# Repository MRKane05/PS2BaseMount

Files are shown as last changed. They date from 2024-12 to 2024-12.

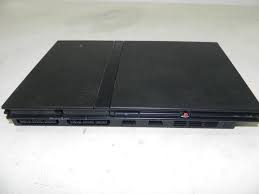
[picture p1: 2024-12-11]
PS2Console.jpeg

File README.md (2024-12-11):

This is a dump of the KiCad project for the Junkstation PS2 project I made a few years ago. I'm really just backing it up for prosperity. 
I'm taking no responsibility for this and it really should be used only as reference.

It's worth noting that there are a couple of mistakes on the board that I haven't fixed:
-The Ethernet wiring for the Mango isn't correct, and troubleshooting it was exceedingly difficult, so much so that I didn't write it down when I got it right, I just put the lid on it
-The Ethernet lines for the Mango shouldn't be pulled down to Ground but pulled to the "R0" pin on the Mango. This allows a successful ethernet connection
-The SD Card slot wired up for game loading through the memory card port is correctly wired

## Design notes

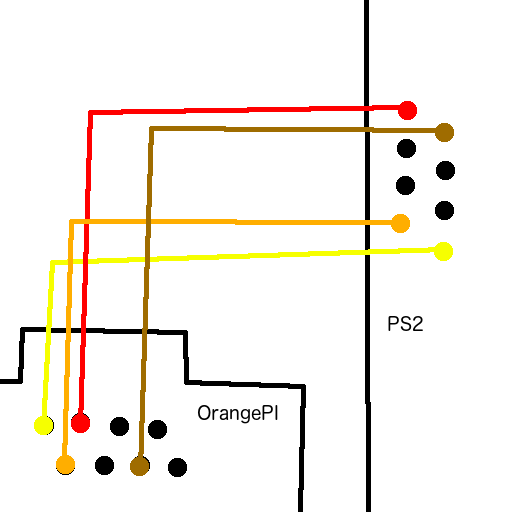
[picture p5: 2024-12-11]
PS2toOrangePi.png

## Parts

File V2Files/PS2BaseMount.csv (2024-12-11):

Comment | Designator | Footprint | LCSC
10U | C1 | Capacitor_SMD:C_1206_3216Metric_Pad1.42x1.75mm_HandSolder
CP_220uF | C10 | Capacitor_THT:CP_Radial_D8.0mm_P3.50mm
470n | C2,C3,C9 | Capacitor_SMD:C_1206_3216Metric_Pad1.42x1.75mm_HandSolder | C1871
C1u | C4,C5,C6 | Capacitor_SMD:C_1206_3216Metric_Pad1.42x1.75mm_HandSolder | C1848
CP_680uF | C7 | Capacitor_THT:CP_Radial_D8.0mm_P2.50mm
C470u | C8 | Capacitor_THT:CP_Radial_D8.0mm_P2.50mm
DIODE | D1 | Crystal:Crystal_SMD_5032-2Pin_5.0x3.2mm_HandSoldering
LED_GREEN | D2 | LED_THT:LED_D3.0mm
LED_YELLOW | D3 | LED_THT:LED_D3.0mm
LED_RED | D4 | LED_THT:LED_D3.0mm
D_Schottky | D5 | Crystal:Crystal_SMD_5032-2Pin_5.0x3.2mm_HandSoldering | C8678
BATT_LED_A | D6 | LED_THT:LED_D3.0mm
BATT_LED_B | D7 | LED_THT:LED_D3.0mm
RJ45 | J1,J5 | PS2BaseMount:RJ45_Floating
Conn_01x06_Female | J2,J8 | Connector_PinHeader_2.54mm:PinHeader_1x06_P2.54mm_Horizontal
USB_B | J4 | PS2BaseMount:USB_A_Custom_Throughhole_MountGuide
DB15_Female_HighDensity | J6 | PS2BaseMount:ScreenBoardArea
INDUCTOR_33uH | L1 | Inductor_SMD:L_12x12mm_H8mm | C169375
PS2AVPort_SideMount | M1 | PS2BaseMount:PS2_AVPort_Complete_MountSilk
PS2AVPort | M2 | PS2BaseMount:PS2_AVPort_Complete
TS_LFT | M3 | PS2BaseMount:JST_1.25_5Pin
TS_RHT | M4 | PS2BaseMount:JST_1.25_5Pin
TRIGGERS_LFT | M5 | PS2BaseMount:JST_1.25_3Pin
TRIGGERS_RIGHT | M6 | PS2BaseMount:JST_1.25_3Pin
Fan | M7 | PS2BaseMount:JST_1.5_2Pin
PS2_MemCardMount | P1 | PS2BaseMount:PS2_MemCardMountPoints
PS2_ControlMount | P2,P3 | PS2BaseMount:PS2_BoardMountFootprint
2N7000 | Q1,Q4,Q5,Q6 | PS2BaseMount:2N7000_HandSolder
Q_NMOS_GDS | Q2 | Package_TO_SOT_THT:TO-220F-3_Vertical
2N2219 | Q3 | PS2BaseMount:2N7000_HandSolder
100K | R1,R4 | Resistor_SMD:R_1206_3216Metric_Pad1.42x1.75mm_HandSolder
220 | R10 | Resistor_SMD:R_1206_3216Metric_Pad1.42x1.75mm_HandSolder
R10K | R11,R12,R13,R17,R18,R19 | Resistor_SMD:R_1206_3216Metric_Pad1.42x1.75mm_HandSolder
R100K | R14,R15 | Resistor_SMD:R_1206_3216Metric_Pad1.42x1.75mm_HandSolder
1K | R2,R6 | Resistor_SMD:R_1206_3216Metric_Pad1.42x1.75mm_HandSolder
4.7K | R5 | Resistor_SMD:R_2010_5025Metric_Pad1.52x2.65mm_HandSolder
4.7K | R7 | Diode_SMD:D_2010_5025Metric_Pad1.52x2.65mm_HandSolder
R220 | R8,R9 | Resistor_SMD:R_1206_3216Metric_Pad1.42x1.75mm_HandSolder
INTERACTION | SW1 | PS2BaseMount:SMT_2X4X3.5MM
START | SW2 | PS2BaseMount:SquishyTact
SELECT | SW3 | PS2BaseMount:SquishyTact
OrangePiZero | U1 | PS2BaseMount:OrangePiZero
RJ14K | U10 | PS2BaseMount:RJ14K_Modified
18650_BatteryMount | U11,U12 | PS2BaseMount:18650_3xHolderV3
DPAD | U13 | PS2BaseMount:DPad_Buttons
RumbleA | U14 | PS2BaseMount:JST_1.5_2Pin
RumbleB | U15 | PS2BaseMount:JST_1.5_2Pin
GNDMount | U7,U16,U24,U25,U26 | PS2BaseMount:GND
ScreenPWM | U17 | PS2BaseMount:JST_1.5_2Pin
PIC_14 | U18 | Package_DIP:DIP-14_W7.62mm_LongPads
PS2_RESET | U19 | PS2BaseMount:GND
PJ30240 | U2 | PS2BaseMount:AudioJack_PJ30240
LM2596T-5 | U20 | Package_TO_SOT_SMD:TO-263-5_TabPin3 | C10002
GND_IN | U21 | PS2BaseMount:MountPoint
BATT_IN | U22 | PS2BaseMount:MountPoint
5vMount | U23 | PS2BaseMount:MountPoint
Audio_Left | U3 | PS2BaseMount:JST_1.5_2Pin
Audio_Right | U4 | PS2BaseMount:JST_1.5_2Pin
PAM8403 | U5 | w_smd_dil:so-16 | C348830
DS18B20 | U6 | Package_TO_SOT_THT:TO-92_Inline
PIC16F18876-I_PT | U8 | PS2BaseMount:PIC16F18876-I_PT
XOST_Buttons | U9 | PS2BaseMount:XOST_ButtonsV2

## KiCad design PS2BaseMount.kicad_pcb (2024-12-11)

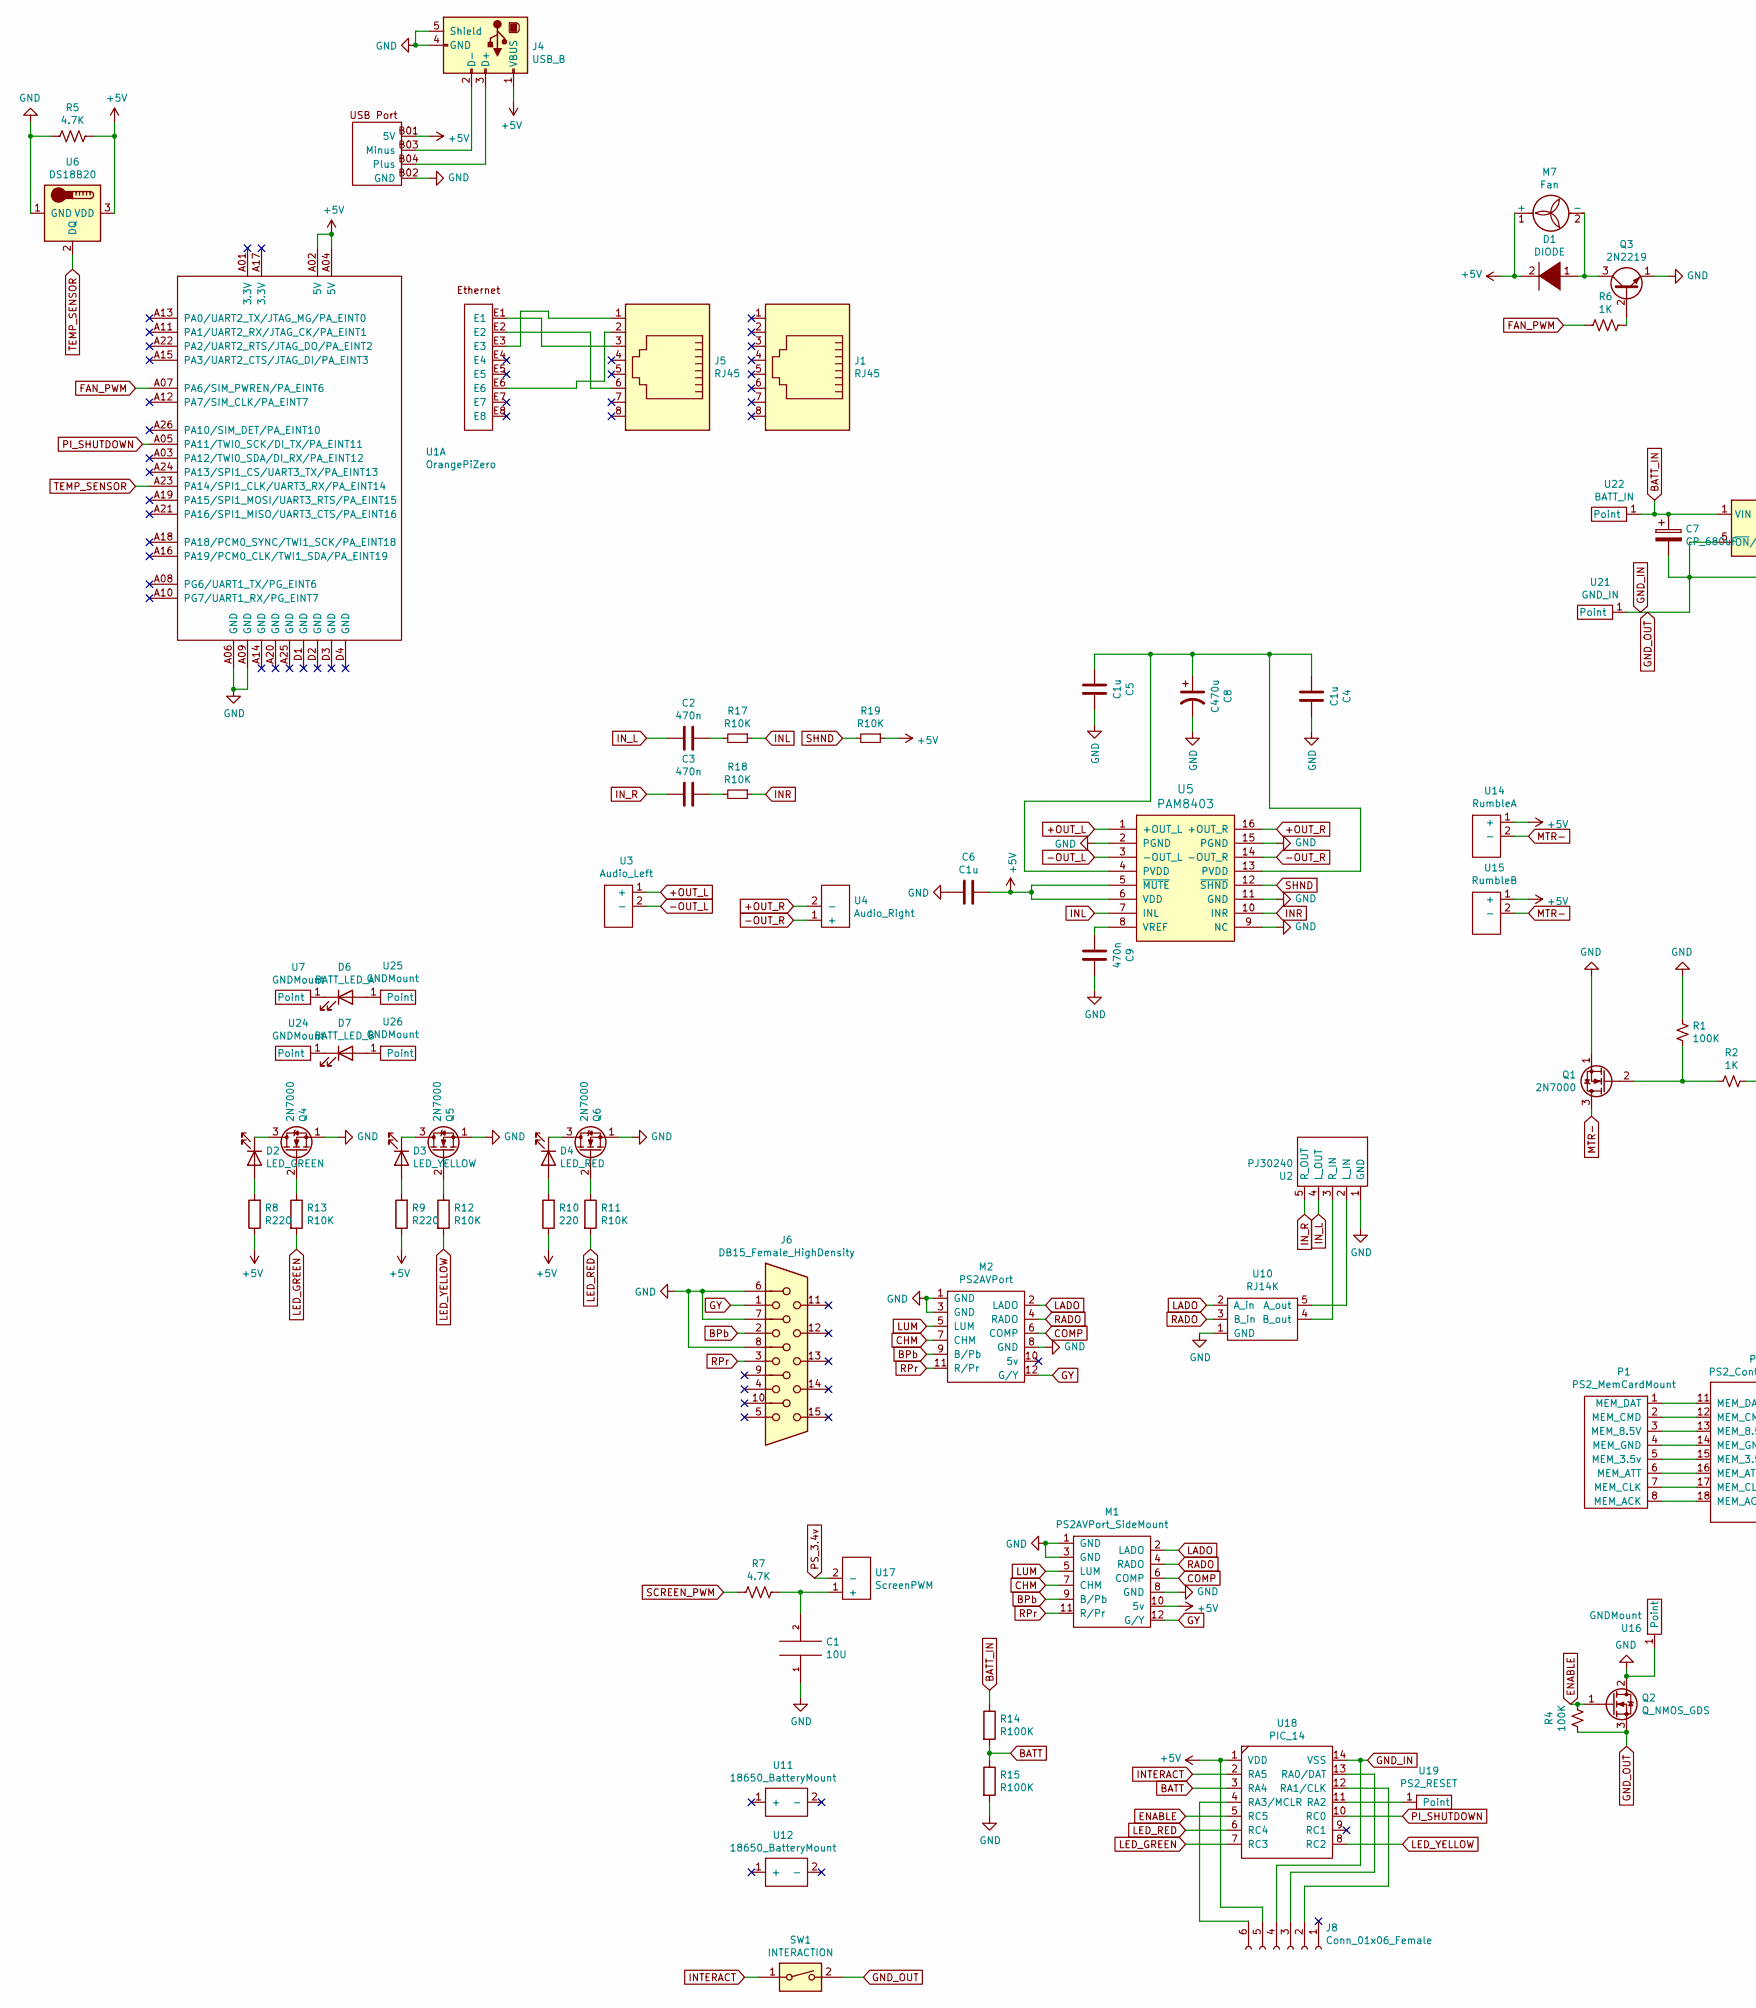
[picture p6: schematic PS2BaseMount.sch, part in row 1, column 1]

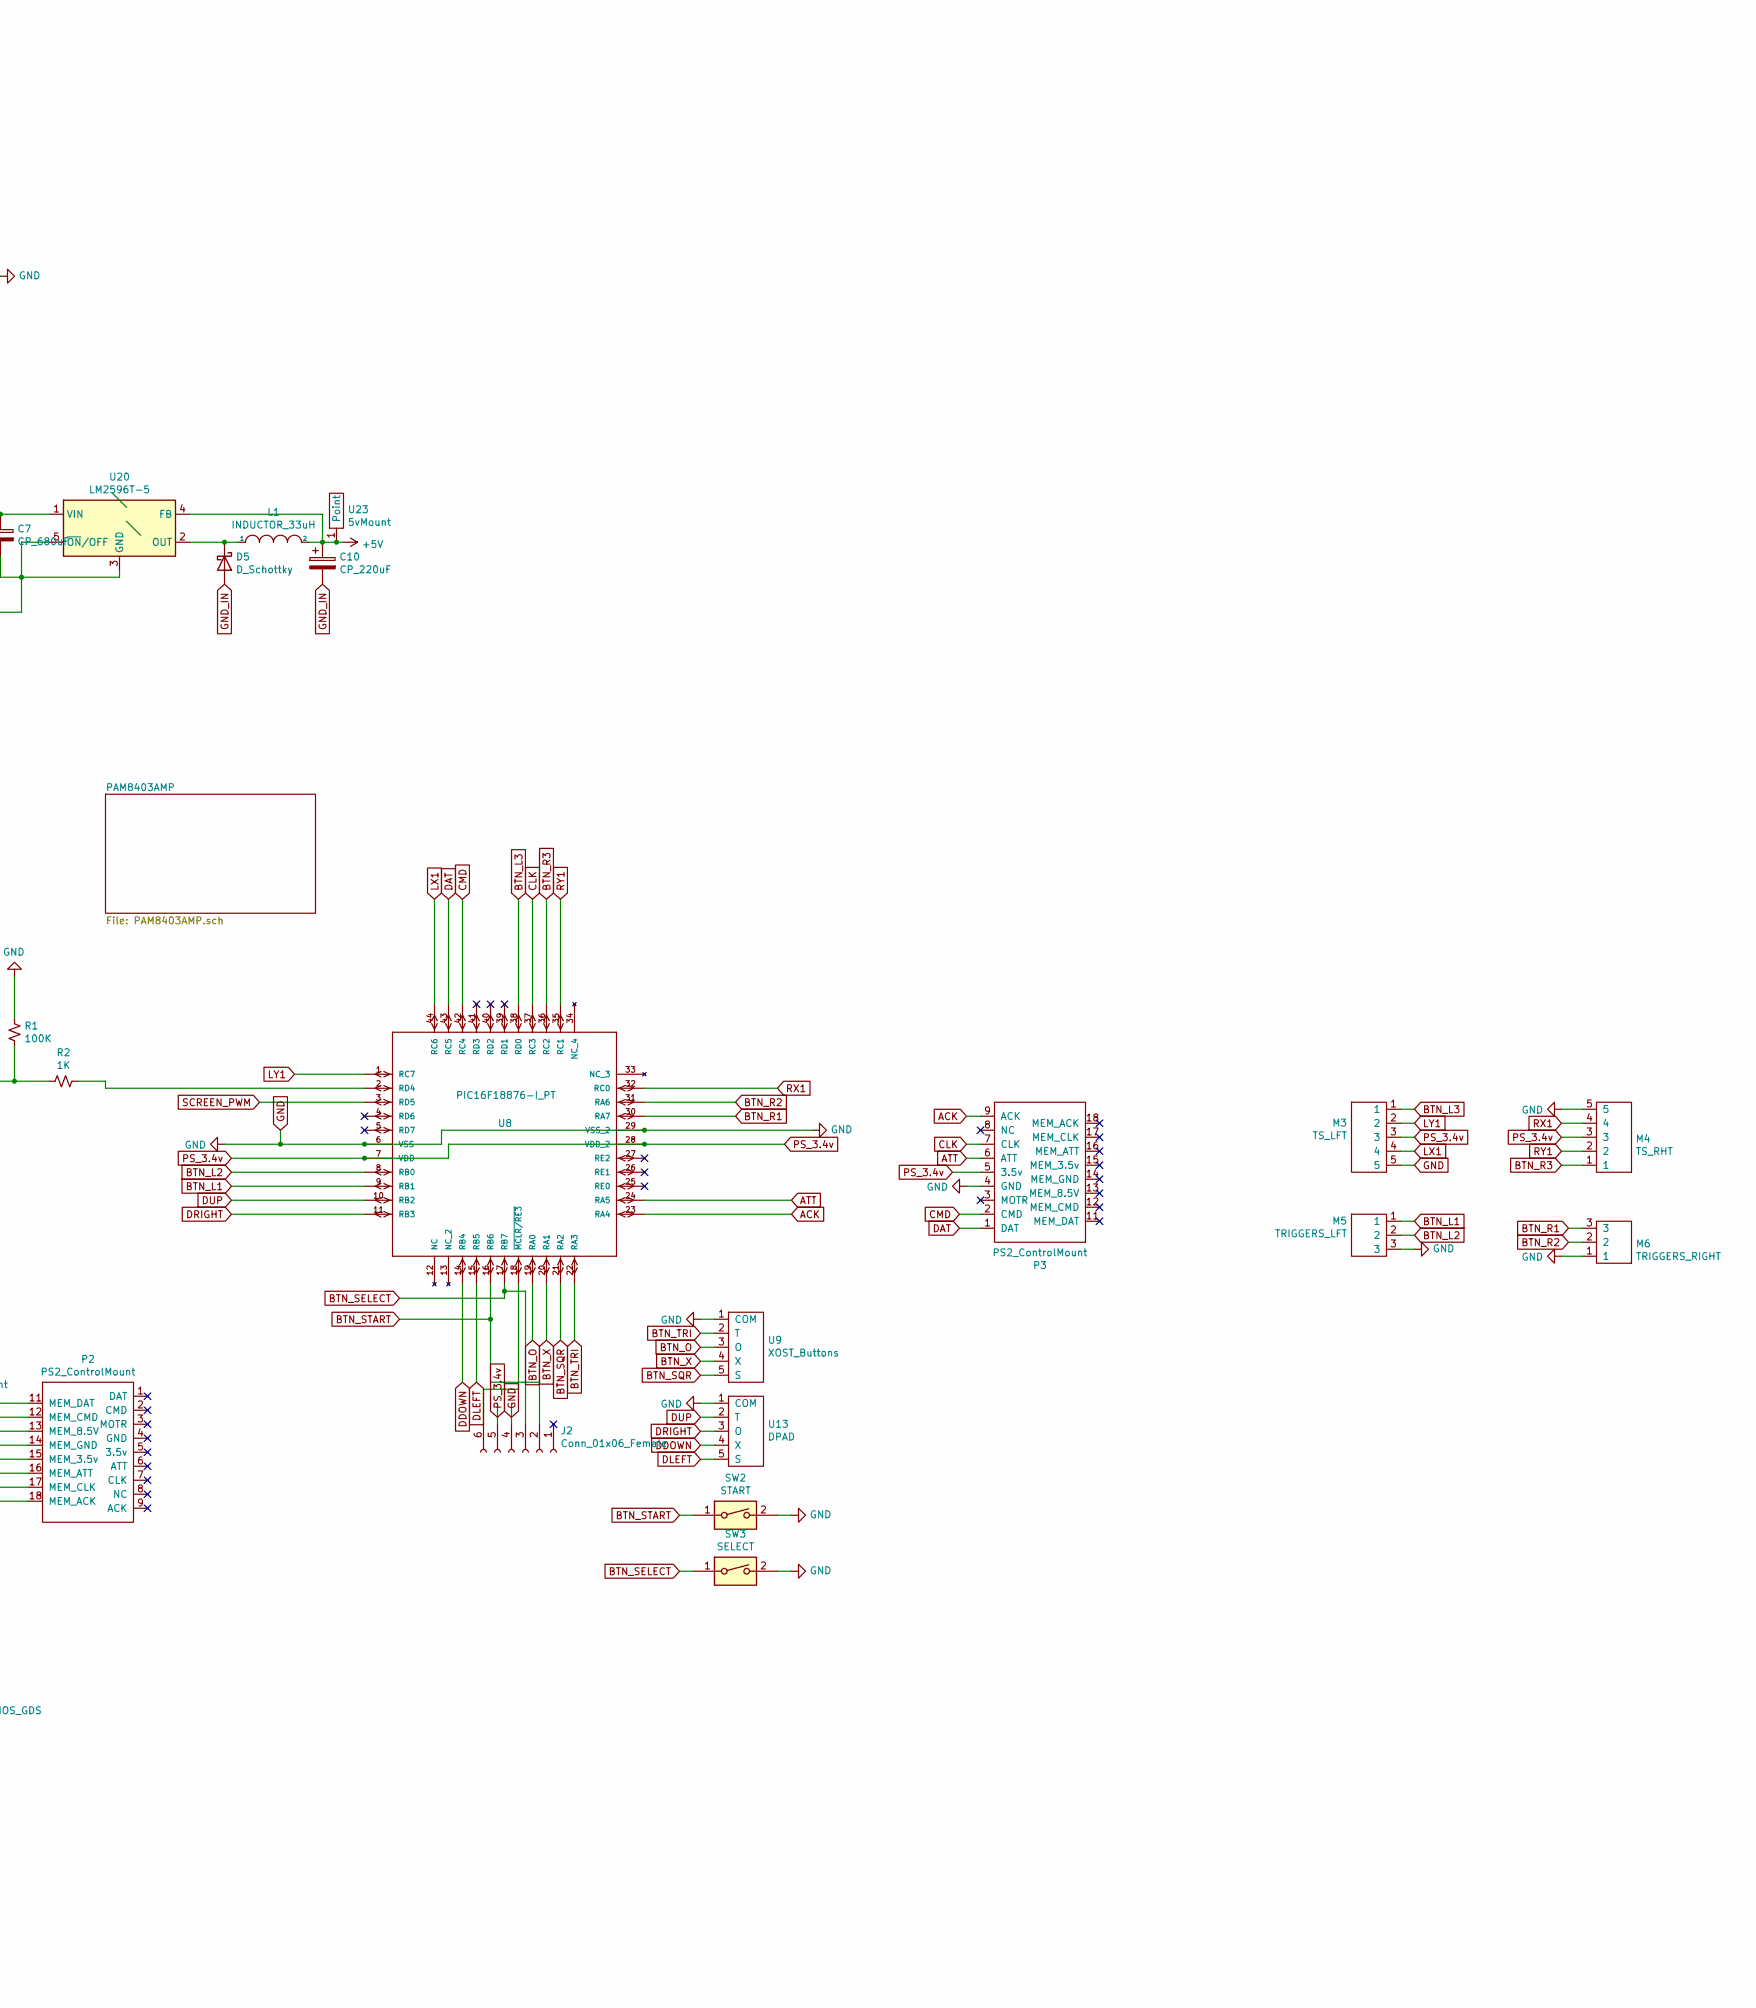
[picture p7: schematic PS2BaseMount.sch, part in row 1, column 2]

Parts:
C1: 10U; C_1206_3216Metric_Pad1.42x1.75mm_HandSolder
C2, C3, C9: 470n; C_1206_3216Metric_Pad1.42x1.75mm_HandSolder; LCSC C1871
C4, C5, C6: C1u; C_1206_3216Metric_Pad1.42x1.75mm_HandSolder; LCSC C1848
C7: CP_680uF; CP_Radial_D8.0mm_P2.50mm
C8: C470u; CP_Radial_D8.0mm_P2.50mm
C10: CP_220uF; CP_Radial_D8.0mm_P3.50mm
D1: DIODE; Crystal_SMD_5032-2Pin_5.0x3.2mm_HandSoldering
D2: LED_GREEN; LED_D3.0mm
D3: LED_YELLOW; LED_D3.0mm
D4: LED_RED; LED_D3.0mm
D5: D_Schottky; Crystal_SMD_5032-2Pin_5.0x3.2mm_HandSoldering; LCSC C8678
D6: BATT_LED_A; LED_D3.0mm
D7: BATT_LED_B; LED_D3.0mm
J1, J5: RJ45; RJ45_Floating
J2, J8: Conn_01x06_Female; PinHeader_1x06_P2.54mm_Horizontal
J4: USB_B; USB_A_Custom_Throughhole_MountGuide
J6: DB15_Female_HighDensity; ScreenBoardArea
L1: INDUCTOR_33uH; L_12x12mm_H8mm; LCSC C169375
M1: PS2AVPort_SideMount; PS2_AVPort_Complete_MountSilk
M2: PS2AVPort; PS2_AVPort_Complete
M3: TS_LFT; JST_1.25_5Pin
M4: TS_RHT; JST_1.25_5Pin
M5: TRIGGERS_LFT; JST_1.25_3Pin
M6: TRIGGERS_RIGHT; JST_1.25_3Pin
M7: Fan; JST_1.5_2Pin
P1: PS2_MemCardMount; PS2_MemCardMountPoints
P2, P3: PS2_ControlMount; PS2_BoardMountFootprint
Q1, Q4, Q5, Q6: 2N7000; 2N7000_HandSolder
Q2: Q_NMOS_GDS; TO-220F-3_Vertical
Q3: 2N2219; 2N7000_HandSolder
R1, R4: 100K; R_1206_3216Metric_Pad1.42x1.75mm_HandSolder
R2, R6: 1K; R_1206_3216Metric_Pad1.42x1.75mm_HandSolder
R5: 4.7K; R_2010_5025Metric_Pad1.52x2.65mm_HandSolder
R7: 4.7K; D_2010_5025Metric_Pad1.52x2.65mm_HandSolder
R8, R9: R220; R_1206_3216Metric_Pad1.42x1.75mm_HandSolder
R10: 220; R_1206_3216Metric_Pad1.42x1.75mm_HandSolder
R11, R12, R13: R10K; R_1206_3216Metric_Pad1.42x1.75mm_HandSolder
R14, R15: R100K; R_1206_3216Metric_Pad1.42x1.75mm_HandSolder
R17, R18, R19: R10K; R_1206_3216Metric_Pad1.42x1.75mm_HandSolder; LCSC C17902
SW1: INTERACTION; SMT_2X4X3.5MM
SW2: START; SquishyTact
SW3: SELECT; SquishyTact
U1: OrangePiZero
U2: PJ30240; AudioJack_PJ30240
U3: Audio_Left; JST_1.5_2Pin
U4: Audio_Right; JST_1.5_2Pin
U5: PAM8403; so-16; LCSC C348830
U6: DS18B20; TO-92_Inline
U7, U16, U24, U25, U26: GNDMount; GND
U8: PIC16F18876-I_PT
U9: XOST_Buttons; XOST_ButtonsV2
U10: RJ14K; RJ14K_Modified
U11, U12: 18650_BatteryMount; 18650_3xHolderV3
U13: DPAD; DPad_Buttons
U14: RumbleA; JST_1.5_2Pin
U15: RumbleB; JST_1.5_2Pin
U17: ScreenPWM; JST_1.5_2Pin
U18: PIC_14; DIP-14_W7.62mm_LongPads
U19: PS2_RESET; GND
U20: LM2596T-5; TO-263-5_TabPin3; LCSC C10002
U21: GND_IN; MountPoint
U22: BATT_IN; MountPoint
U23: 5vMount; MountPoint

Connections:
+5V: C6.1, C10.1, D1.2 (A), J4.1 (VBUS), J8.5, L1.2, M1.10 (5v), M7.1 (+), R5.1, R8.1, R9.1, R10.1, R19.1, U1.A02 (5V), U1.A04 (5V), U1.B01 (5V), U5.5 (~MUTE), U5.6 (VDD), U6.3 (VDD), U14.1 (+), U15.1 (+), U18.1 (VDD), U20.4 (FB), U23.1
+OUT_L: U3.1 (+), U5.1 (+OUT_L)
+OUT_R: U4.2 (-), U5.16 (+OUT_R)
-OUT_L: U3.2 (-), U5.3 (-OUT_L)
-OUT_R: U4.1 (+), U5.14 (-OUT_R)
ACK: P3.9 (ACK), U8.23 (RA4)
ATT: P3.6 (ATT), U8.24 (RA5)
BATT: R14.2, R15.1, U18.3 (RA4)
BATT_IN: C7.1, R14.1, U20.1 (VIN), U22.1
BPb: J6.2, M1.9 (B/Pb), M2.9 (B/Pb)
BTN_L1: M5.1, U8.9 (RB1)
BTN_L2: M5.2, U8.8 (RB0)
BTN_L3: M3.1, U8.38 (RD0)
BTN_O: U8.19 (RA0), U9.3 (O)
BTN_R1: M6.3, U8.30 (RA7)
BTN_R2: M6.2, U8.31 (RA6)
BTN_R3: M4.1, U8.36 (RC2)
BTN_SELECT: J2.3, SW3.1, U8.17 (RB7)
BTN_SQR: U8.21 (RA2), U9.5 (S)
BTN_START: J2.2, SW2.1, U8.16 (RB6)
BTN_TRI: U8.22 (RA3), U9.2 (T)
BTN_X: U8.20 (RA1), U9.4 (X)
CHM: M1.7 (CHM), M2.7 (CHM)
CLK: P3.7 (CLK), U8.37 (RC3)
CMD: P3.2 (CMD), U8.42 (RC4)
COMP: M1.6 (COMP), M2.6 (COMP)
DAT: P3.1 (DAT), U8.43 (RC5)
DDOWN: U8.14 (RB4), U13.4 (X)
DLEFT: U8.15 (RB5), U13.5 (S)
DRIGHT: U8.11 (RB3), U13.3 (O)
DUP: U8.10 (RB2), U13.2 (T)
ENABLE: Q2.1 (G), R4.1, U18.5 (RC5)
FAN_PWM: R6.2, U1.A07 (PA6/SIM_PWREN/PA_EINT6)
GND: C1.1, C4.1, C5.1, C6.2, C8.2, C9.1, J2.4, J4.4 (GND), J4.5 (Shield), J6.6, J6.7, J6.8, M1.1 (GND), M1.3 (GND), M1.8 (GND), M2.1 (GND), M2.3 (GND), M2.8 (GND), M3.5, M4.5, M5.3, M6.1, P3.4 (GND), Q1.1 (S), Q2.2 (D), Q3.1 (E), Q4.1 (S), Q5.1 (S), Q6.1 (S), R1.1, R5.2, R15.2, SW2.2, SW3.2, U1.A06 (GND), U1.A09 (GND), U1.B02 (GND), U2.1 (GND), U5.2 (PGND), U5.9 (NC), U5.11 (GND), U5.15 (PGND), U6.1 (GND), U8.6 (VSS), U8.29 (VSS_2), U9.1 (COM), U10.1 (GND), U13.1 (COM), U16.1
GND_IN: C7.2, C10.2, D5.2 (A), J8.4, Q2.3 (S), R4.2, SW1.2, U18.14 (VSS), U20.3 (GND), U20.5 (~ON~/OFF), U21.1
GY: J6.1, M1.12 (G/Y), M2.12 (G/Y)
INL: R17.1, U5.7 (INL)
INR: R18.1, U5.10 (INR)
INTERACT: SW1.1, U18.2 (RA5)
IN_L: C2.2, U2.4 (L_OUT)
IN_R: C3.2, U2.5 (R_OUT)
LADO: M1.2 (LADO), M2.2 (LADO), U10.2 (A_in)
LED_GREEN: R13.2, U18.7 (RC3)
LED_RED: R11.2, U18.6 (RC4)
LED_YELLOW: R12.2, U18.8 (RC2)
LUM: M1.5 (LUM), M2.5 (LUM)
LX1: M3.4, U8.44 (RC6)
LY1: M3.2, U8.1 (RC7)
MTR-: Q1.3 (D), U14.2 (-), U15.2 (-)
unnamed: C1.2, R7.1, U17.1 (+)
unnamed: C2.1, R17.2
unnamed: C3.1, R18.2
unnamed: C4.2, C5.2, C8.1, U5.4 (PVDD), U5.13 (PVDD)
unnamed: C9.2, U5.8 (VREF)
unnamed: D1.1 (K), M7.2 (-), Q3.3 (C)
unnamed: D2.1 (K), Q4.3 (D)
unnamed: D2.2 (A), R8.2
unnamed: D3.1 (K), Q5.3 (D)
unnamed: D3.2 (A), R9.2
unnamed: D4.1 (K), Q6.3 (D)
unnamed: D4.2 (A), R10.2
unnamed: D5.1 (K), L1.1, U20.2 (OUT)
unnamed: D6.1 (K), U7.1
unnamed: D6.2 (A), U25.1
unnamed: D7.1 (K), U24.1
unnamed: D7.2 (A), U26.1
unnamed: J2.6, U8.18 (~MCLR/RE3)
unnamed: J4.2 (D-), U1.B03 (Minus)
unnamed: J4.3 (D+), U1.B04 (Plus)
unnamed: J5.1, U1.E3
unnamed: J5.2, U1.E6
unnamed: J5.3, U1.E1
unnamed: J5.6, U1.E2
unnamed: J8.2, U18.12 (RA1/CLK)
unnamed: J8.3, U18.13 (RA0/DAT)
unnamed: J8.6, U18.4 (RA3/MCLR)
unnamed: P1.1 (MEM_DAT), P2.11 (MEM_DAT)
unnamed: P1.2 (MEM_CMD), P2.12 (MEM_CMD)
unnamed: P1.3 (MEM_8.5V), P2.13 (MEM_8.5V)
unnamed: P1.4 (MEM_GND), P2.14 (MEM_GND)
unnamed: P1.5 (MEM_3.5v), P2.15 (MEM_3.5v)
unnamed: P1.6 (MEM_ATT), P2.16 (MEM_ATT)
unnamed: P1.7 (MEM_CLK), P2.17 (MEM_CLK)
unnamed: P1.8 (MEM_ACK), P2.18 (MEM_ACK)
unnamed: Q1.2 (G), R1.2, R2.2
unnamed: Q3.2 (B), R6.1
unnamed: Q4.2 (G), R13.1
unnamed: Q5.2 (G), R12.1
unnamed: Q6.2 (G), R11.1
unnamed: R2.1, U8.2 (RD4)
unnamed: U2.3 (R_IN), U10.4 (B_out)
unnamed: U2.2 (L_IN), U10.5 (A_out)
unnamed: U18.11 (RA2), U19.1
PI_SHUTDOWN: U1.A05 (PA11/TWI0_SCK/DI_TX/PA_EINT11), U18.10 (RC0)
PS_3.4v: J2.5, M3.3, M4.3, P3.5 (3.5v), U8.7 (VDD), U8.28 (VDD_2), U17.2 (-)
RADO: M1.4 (RADO), M2.4 (RADO), U10.3 (B_in)
RPr: J6.3, M1.11 (R/Pr), M2.11 (R/Pr)
RX1: M4.4, U8.32 (RC0)
RY1: M4.2, U8.35 (RC1)
SCREEN_PWM: R7.2, U8.3 (RD5)
SHND: R19.2, U5.12 (~SHND)
TEMP_SENSOR: U1.A23 (PA14/SPI1_CLK/UART3_RX/PA_EINT14), U6.2 (DQ)

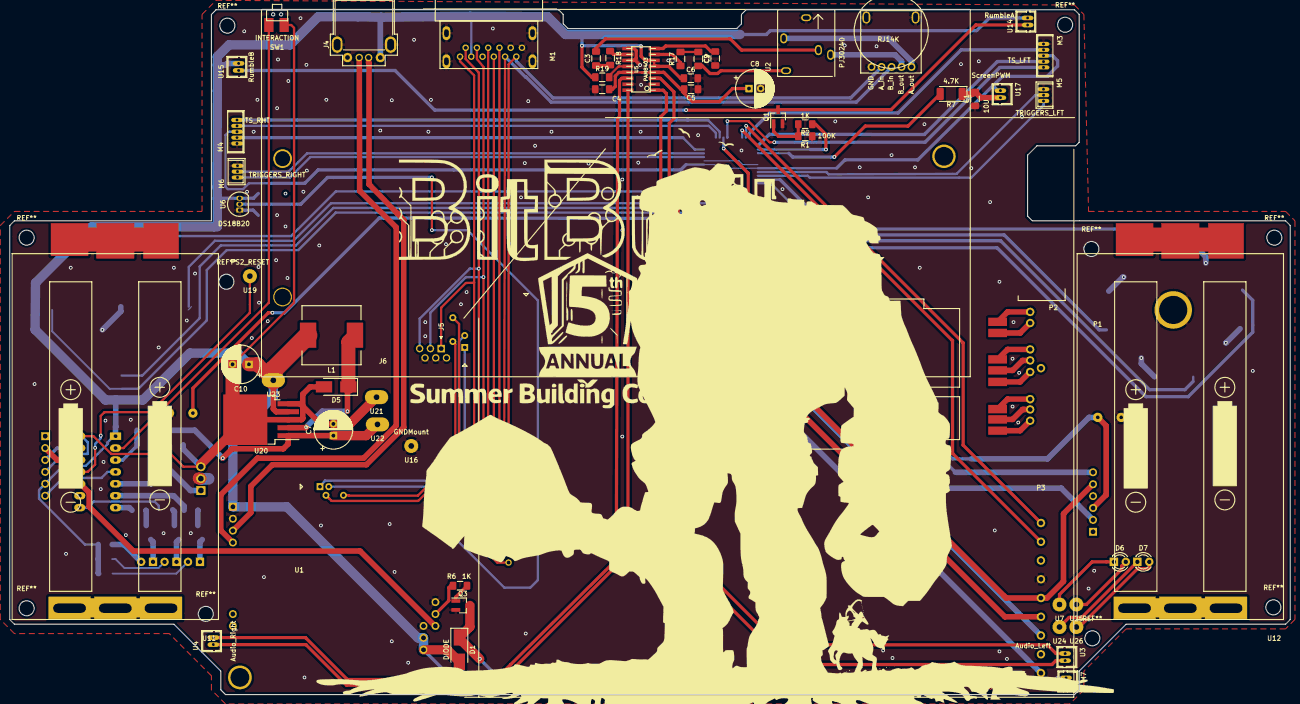
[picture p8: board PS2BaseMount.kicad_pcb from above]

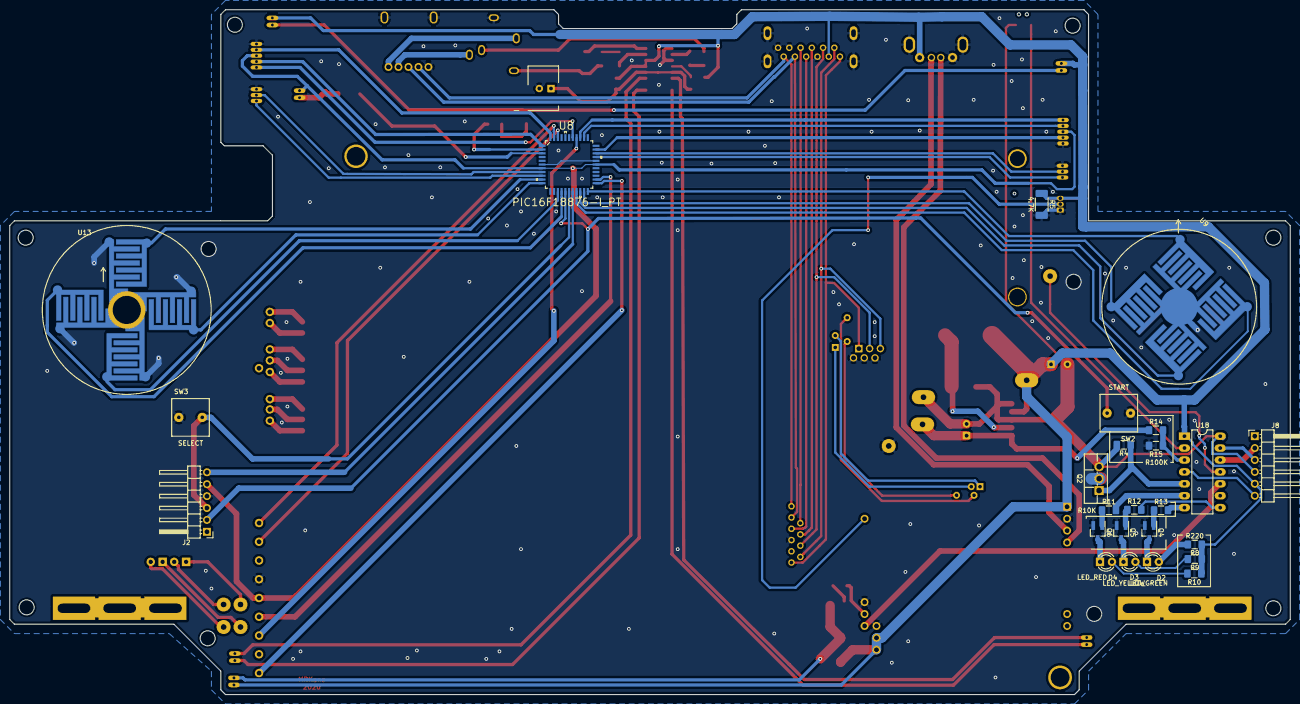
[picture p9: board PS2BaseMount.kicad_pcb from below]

Board: 2 copper layers, 273.0 x 146.0 mm, 86 parts (25 on the bottom side), 102 nets.

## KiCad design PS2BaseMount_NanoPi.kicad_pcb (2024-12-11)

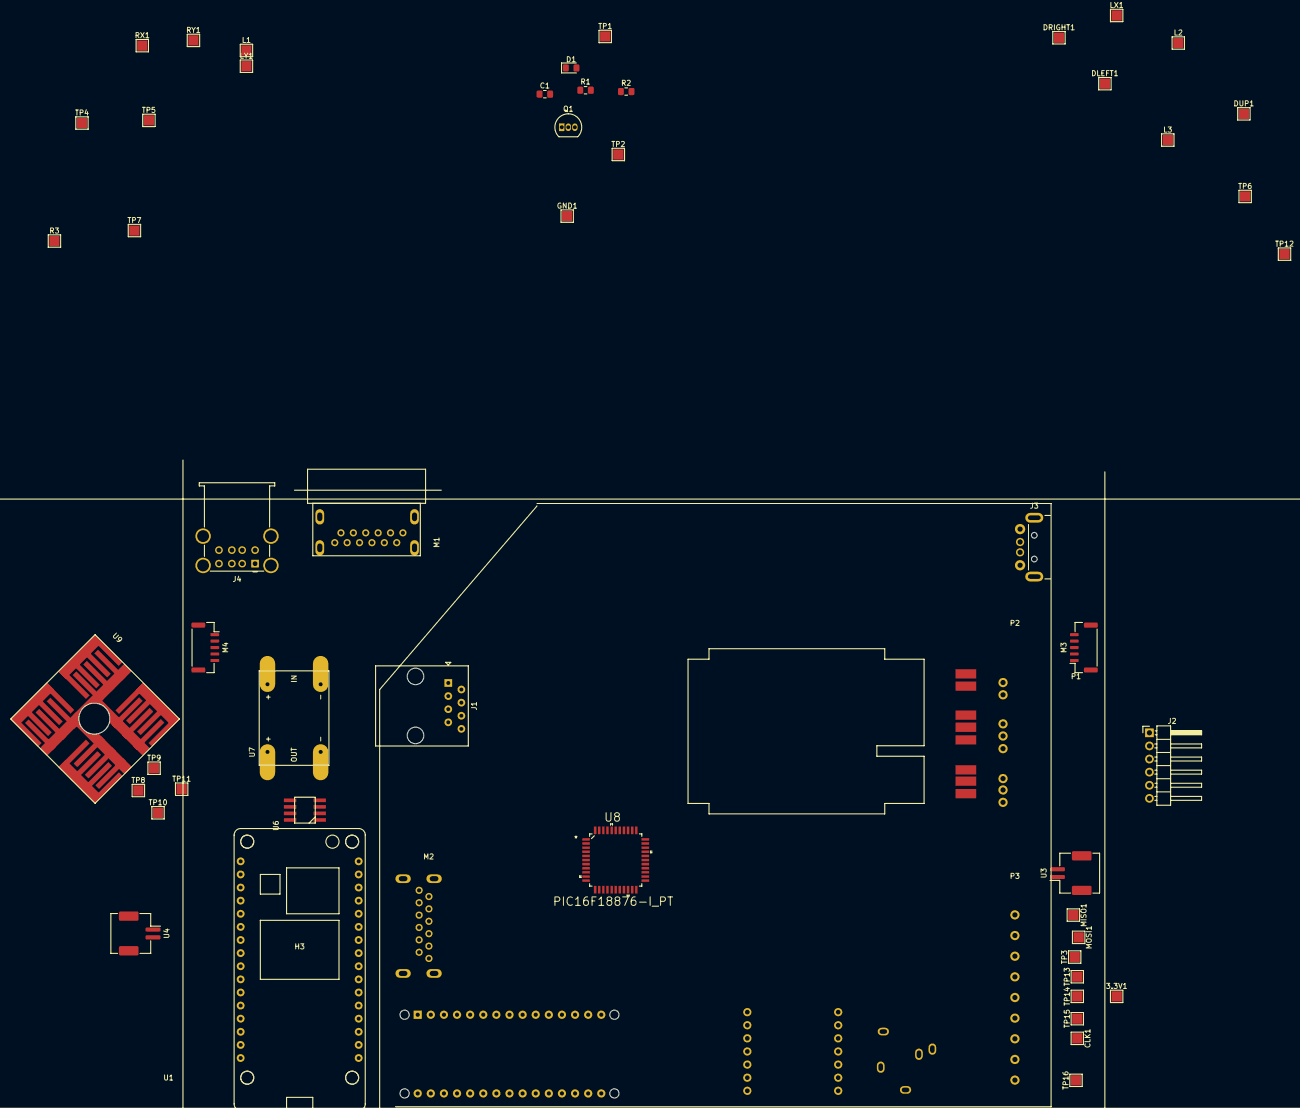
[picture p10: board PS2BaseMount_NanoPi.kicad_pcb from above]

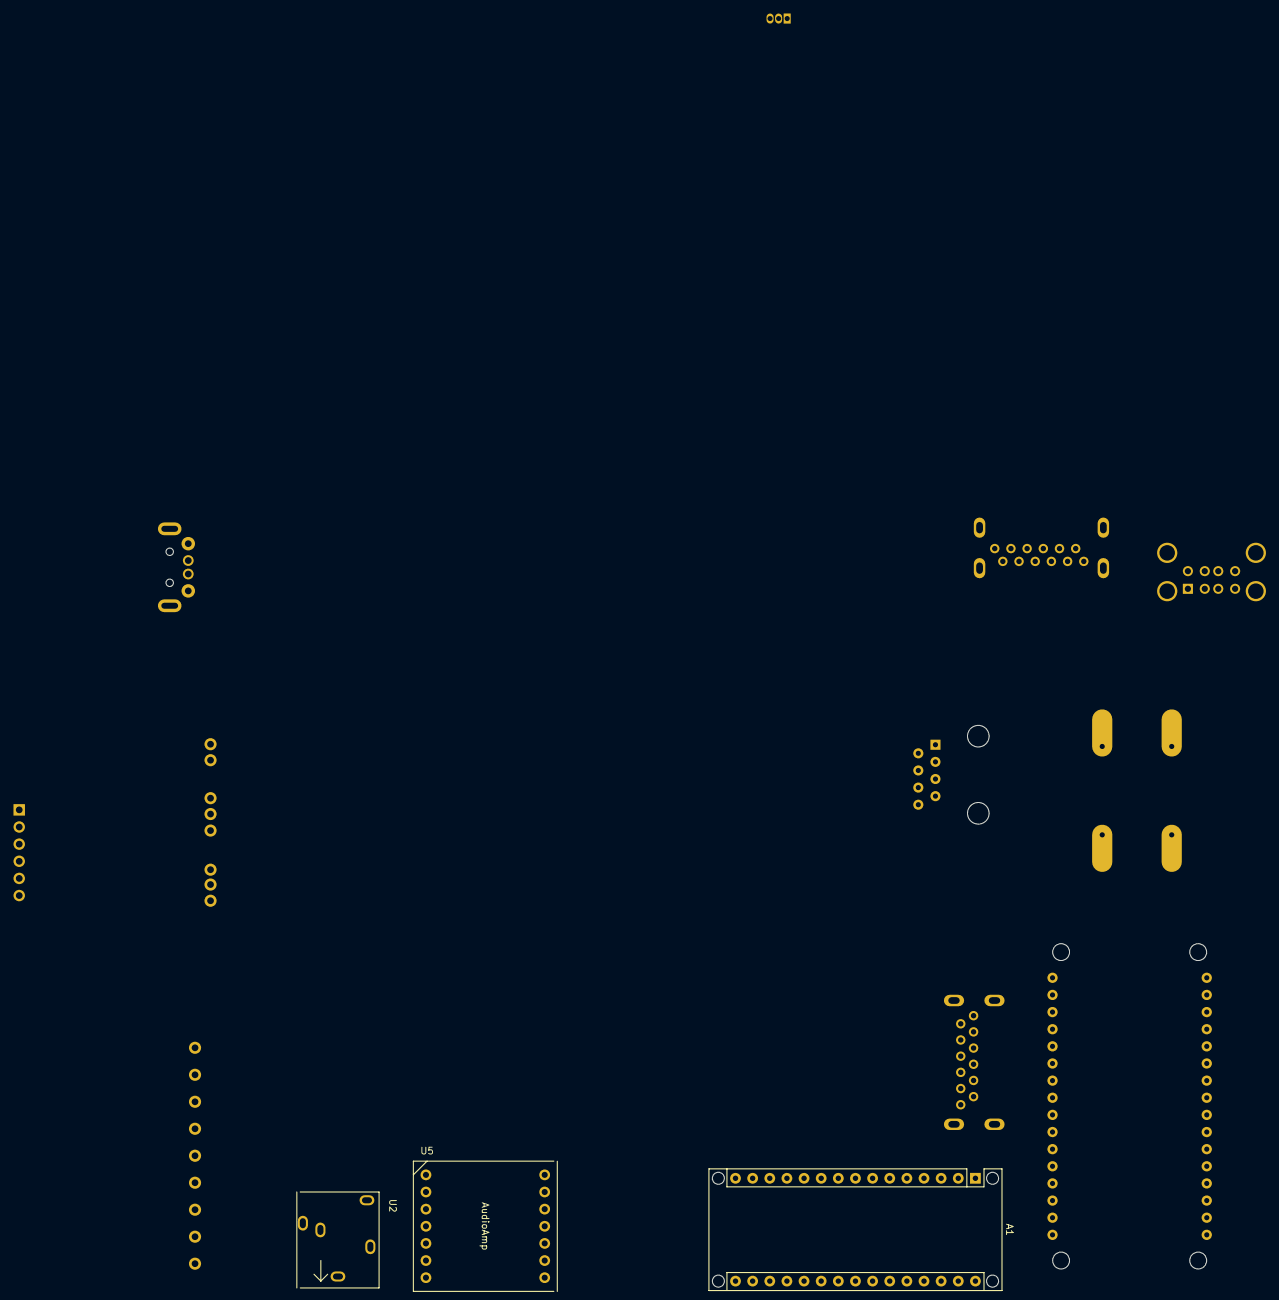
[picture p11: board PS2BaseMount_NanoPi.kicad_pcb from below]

Board: 2 copper layers, 58 parts (3 on the bottom side), 46 nets, no tracks yet.

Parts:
3.3V1: TP6; TestPoint_Pad_2.0x2.0mm
A1: Arduino_Nano_v3.x; Arduino_Nano_WithMountingHoles
C1: 10uF; C_0805_2012Metric_Pad1.15x1.40mm_HandSolder
CLK1: TP19; TestPoint_Pad_2.0x2.0mm
D1: 1N58XX; D_0805_2012Metric_Pad1.15x1.40mm_HandSolder
DLEFT1: TP7; TestPoint_Pad_2.0x2.0mm
DRIGHT1: TP8; TestPoint_Pad_2.0x2.0mm
DUP1: TP27; TestPoint_Pad_2.0x2.0mm
GND1: TP5; TestPoint_Pad_2.0x2.0mm
J1: RJ45; RJ45_Amphenol_54602-x08_Horizontal
J2: Conn_01x06_Female; PinHeader_1x06_P2.54mm_Horizontal
J3: USB_B; USB_A_Custom_Throughhole
J4: USB_A_Dual; USB_A_Wuerth_61400826021_Horizontal_Stacked
L1: TP9; TestPoint_Pad_2.0x2.0mm
L2: TP10; TestPoint_Pad_2.0x2.0mm
L3: TP20; TestPoint_Pad_2.0x2.0mm
LX1: TP26; TestPoint_Pad_2.0x2.0mm
LY1: TP23; TestPoint_Pad_2.0x2.0mm
M1: PS2AVPort_SideMount; PS2_AVPort_Complete_MountSilk
M2: PS2AVPort; PS2_AVPort_Complete
M3: TS_LFT; JST_GH_SM05B-GHS-TB_1x05-1MP_P1.25mm_Horizontal
M4: TS_RHT; JST_GH_SM05B-GHS-TB_1x05-1MP_P1.25mm_Horizontal
MISO1: TP12; TestPoint_Pad_2.0x2.0mm
MOSI1: TP13; TestPoint_Pad_2.0x2.0mm
P1: PS2_MemCardMount; PS2_MemCardMountPoints
P2, P3: PS2_ControlMount; PS2_BoardMountFootprint
Q1: 2N7000; TO-92_Inline
R1: 100K; R_0805_2012Metric_Pad1.15x1.40mm_HandSolder
R2: 1K; R_0805_2012Metric_Pad1.15x1.40mm_HandSolder
R3: TP18; TestPoint_Pad_2.0x2.0mm
RX1: TP11; TestPoint_Pad_2.0x2.0mm
RY1: TP4; TestPoint_Pad_2.0x2.0mm
TP1: MTR-; TestPoint_Pad_2.0x2.0mm
TP2: MTR+; TestPoint_Pad_2.0x2.0mm
TP3: 8.5V; TestPoint_Pad_2.0x2.0mm
TP4: R1; TestPoint_Pad_2.0x2.0mm
TP5: R2; TestPoint_Pad_2.0x2.0mm
TP6: SL; TestPoint_Pad_2.0x2.0mm
TP7: ST; TestPoint_Pad_2.0x2.0mm
TP8: SQ; TestPoint_Pad_2.0x2.0mm
TP9: TRI; TestPoint_Pad_2.0x2.0mm
TP10: X; TestPoint_Pad_2.0x2.0mm
TP11: CIR; TestPoint_Pad_2.0x2.0mm
TP12: DDOWN; TestPoint_Pad_2.0x2.0mm
TP13: GND; TestPoint_Pad_2.0x2.0mm
TP14: 3.3V; TestPoint_Pad_2.0x2.0mm
TP15: CS; TestPoint_Pad_2.0x2.0mm
TP16: ACK; TestPoint_Pad_2.0x2.0mm
U1: NanoPiDUO2; NanoPIDUO2
U2: PJ30240; AudioJack_PJ30240
U3: Audio_Left; JST_ZE_SM02B-ZESS-TBT_1x02-1MP_P1.50mm_Horizontal
U4: Audio_Right; JST_ZE_SM02B-ZESS-TBT_1x02-1MP_P1.50mm_Horizontal
U5: AudioAmp; PAM8803_AudioAmp
U6: DMosfet_AO9926B; DualMosfet AO9926B
U7: 5VBuckBoost; PS2BuckBoost
U8: PIC16F18876-I_PT
U9: XOST_Buttons

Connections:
GND: GND1.1, J2.4, P3.4, Q1.1, R1.1, TP13.1, U2.1, U3.MP, U4.MP, U8.6, U8.29
unnamed: C1.1, D1.2, Q1.3, TP1.1
unnamed: C1.2, D1.1, P3.3, TP2.1, TP3.1
unnamed: CLK1.1, P3.7, U8.37
unnamed: DLEFT1.1, U8.8
unnamed: DRIGHT1.1, U8.9
unnamed: DUP1.1, U8.31
unnamed: J2.2, TP6.1, U8.16
unnamed: J2.3, TP7.1, U8.17
unnamed: J2.6, U8.18
unnamed: L1.1, U8.10
unnamed: L2.1, U8.11
unnamed: L3.1, U8.36
unnamed: LX1.1, U8.32
unnamed: LY1.1, U8.35
unnamed: M2.2, U5.8
unnamed: M2.4, U5.10
unnamed: MISO1.1, P3.1, U8.43
unnamed: MOSI1.1, P3.2, U8.42
unnamed: P1.1, P2.11
unnamed: P1.2, P2.12
unnamed: P1.3, P2.13
unnamed: P1.4, P2.14
unnamed: P1.5, P2.15
unnamed: P1.6, P2.16
unnamed: P1.7, P2.17
unnamed: P1.8, P2.18
unnamed: P3.6, TP15.1, U8.24
unnamed: P3.9, TP16.1, U8.23
unnamed: Q1.2, R1.2, R2.2
unnamed: R2.1, U8.2
unnamed: R3.1, U8.38
unnamed: RX1.1, U8.44
unnamed: RY1.1, U8.1
unnamed: TP4.1, U8.14
unnamed: TP5.1, U8.15
unnamed: TP8.1, U8.19, U9.5
unnamed: TP9.1, U8.20, U9.2
unnamed: TP10.1, U8.21, U9.4
unnamed: TP11.1, U8.22, U9.3
unnamed: TP12.1, U8.30
unnamed: U2.2, U3.1, U5.5
unnamed: U2.3, U4.1, U5.7
unnamed: U3.2, U5.4
unnamed: U4.2, U5.6
Vdd: 3.3V1.1, J2.5, P3.5, TP14.1, U8.7, U8.28

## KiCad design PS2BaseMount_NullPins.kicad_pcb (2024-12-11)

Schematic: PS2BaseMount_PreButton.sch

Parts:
A1: Arduino_Nano_v3.x; Arduino_Nano_WithMountingHoles
J1: USB_B; USB_A_Custom_Throughhole
J2: USB_A_Dual; USB_A_Wuerth_61400826021_Horizontal_Stacked
J3: RJ45; RJ45_Amphenol_54602-x08_Horizontal
M1: PS2AVPort; PS2_AVPort_Complete
M2: TS_LFT; JST_GH_SM05B-GHS-TB_1x05-1MP_P1.25mm_Horizontal
M3: TS_RHT; JST_GH_SM05B-GHS-TB_1x05-1MP_P1.25mm_Horizontal
M4: Fan; 2Point_Mount
M5: PS2AVPort_SideMount; PS2_AVPort_Complete_MountSilk
P1, P2: PS2_ControlMount; PS2_BoardMountFootprint
P3: PS2_MemCardMount; PS2_MemCardMountPoints
Q1: MJE3305; TO-126-3_Vertical
R1: 4.7K; R_2010_5025Metric_Pad1.52x2.65mm_HandSolder
R2: 1K; R_2512_6332Metric_Pad1.52x3.35mm_HandSolder
R3: Fan_J+; SolderJumper-2_P1.3mm_Open_RoundedPad1.0x1.5mm
R4: Fan_J-; SolderJumper-2_P1.3mm_Open_RoundedPad1.0x1.5mm
RV1: R_POT_US; Potentiometer_Triwood_RM-065
TH1: Thermistor_PTC; 2Point_Mount
U1: AudioAmp; PAM8803_AudioAmp
U2: LM358; LM358(SMD)
U3: PJ30240; AudioJack_PJ30240
U4: Audio_Left; JST_ZE_SM02B-ZESS-TBT_1x02-1MP_P1.50mm_Horizontal
U5: Audio_Right; JST_ZE_SM02B-ZESS-TBT_1x02-1MP_P1.50mm_Horizontal
m1: 10P_LFT; Hirose_FH12-10S-0.5SH_1x10-1MP_P0.50mm_Horizontal
m2: 10P_RHT; Hirose_FH12-10S-0.5SH_1x10-1MP_P0.50mm_Horizontal

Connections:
+5V: R1.1, R3.1, RV1.1, U2.8
GND: R4.1, RV1.3, TH1.2, U2.4, U3.1, U4.MP, U5.MP
unnamed: M1.2, U1.8
unnamed: M1.4, U1.10
unnamed: M4.1 (+), Q1.3
unnamed: M4.2 (-), R4.2
unnamed: Q1.1, R2.1
unnamed: Q1.2, R3.2
unnamed: R1.2, TH1.1, U2.2
unnamed: R2.2, U2.1
unnamed: RV1.2, U2.3
unnamed: U1.4, U4.2
unnamed: U1.5, U3.2, U4.1
unnamed: U1.6, U5.2
unnamed: U1.7, U3.3, U5.1

Board: 2 copper layers, 24 parts (1 on the bottom side), 15 nets, no tracks yet.

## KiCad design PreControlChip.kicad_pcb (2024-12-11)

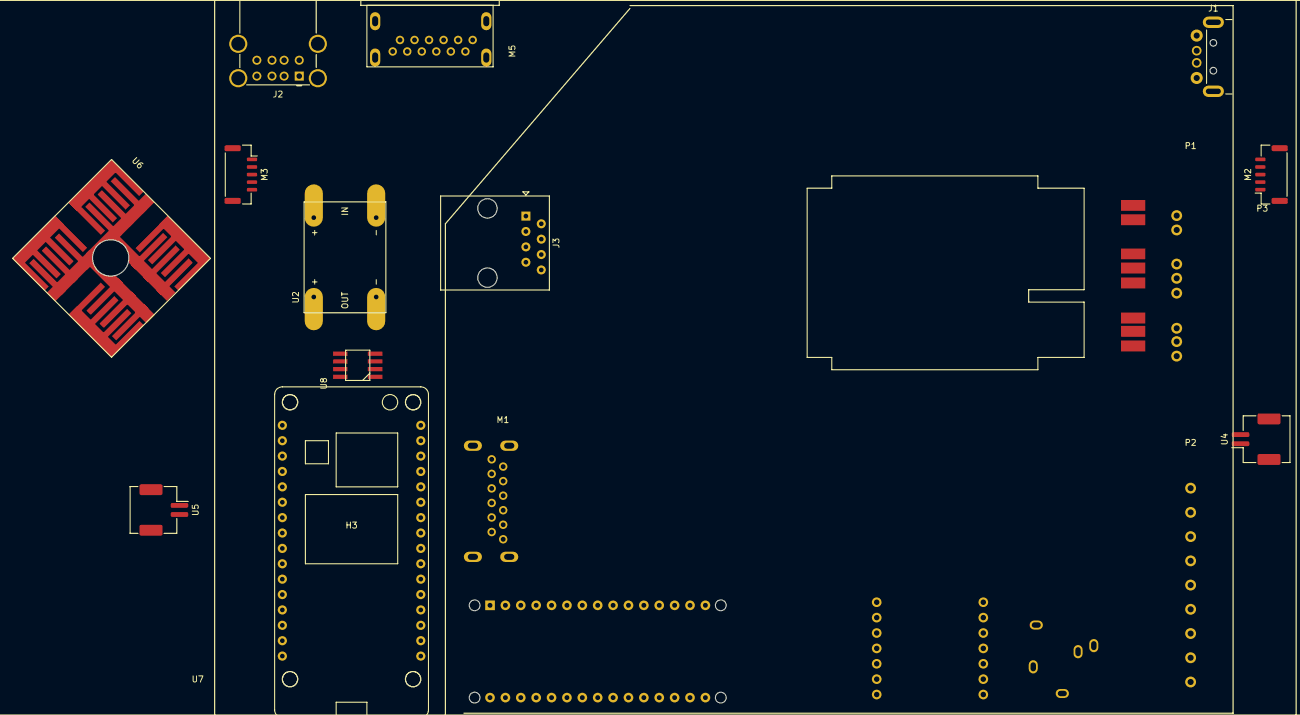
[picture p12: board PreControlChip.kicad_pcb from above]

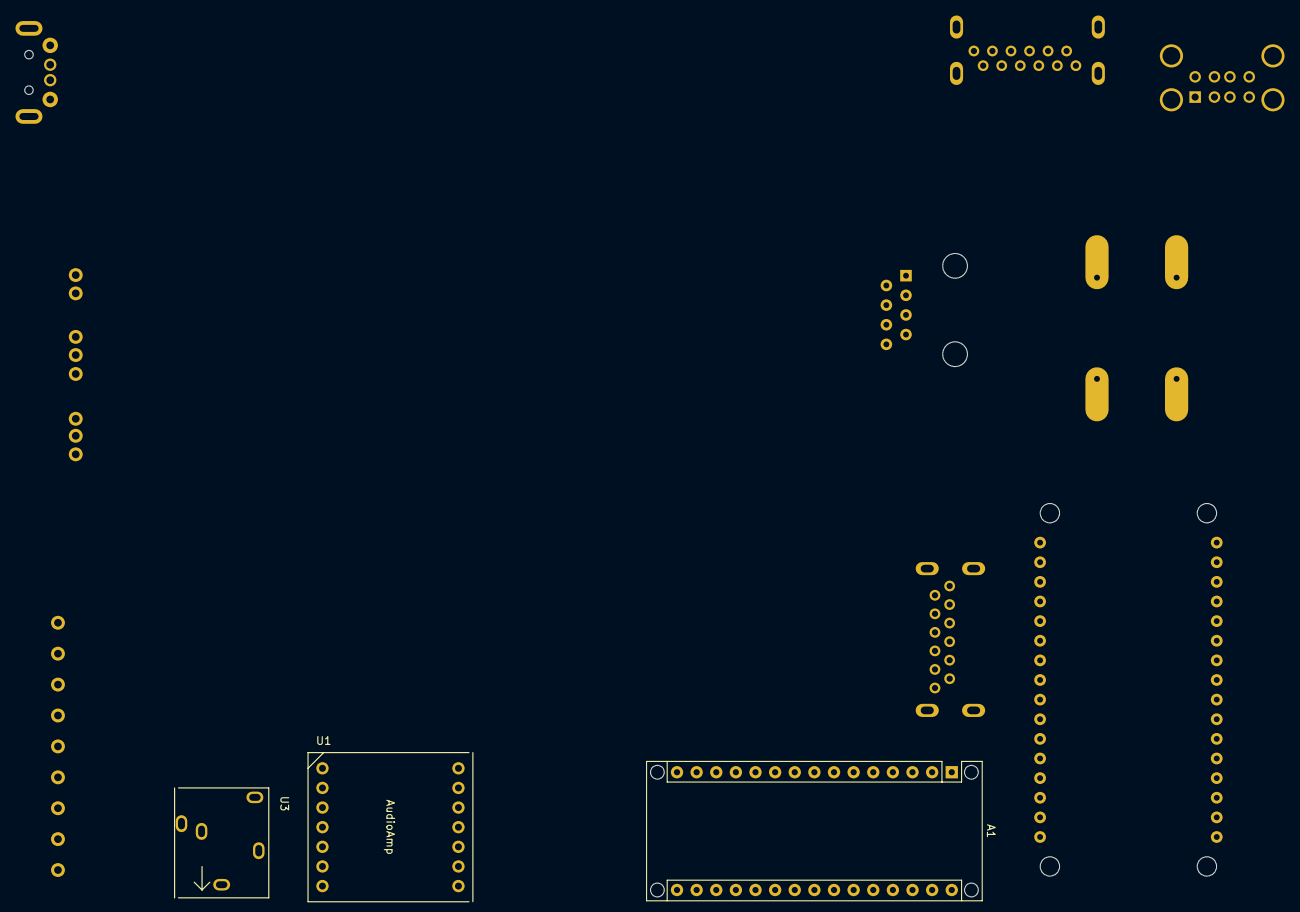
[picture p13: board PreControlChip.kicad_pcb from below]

Board: 2 copper layers, 19 parts (3 on the bottom side), 15 nets, no tracks yet.

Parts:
A1: Arduino_Nano_v3.x; Arduino_Nano_WithMountingHoles
J1: USB_B; USB_A_Custom_Throughhole
J2: USB_A_Dual; USB_A_Wuerth_61400826021_Horizontal_Stacked
J3: RJ45; RJ45_Amphenol_54602-x08_Horizontal
M1: PS2AVPort; PS2_AVPort_Complete
M2: TS_LFT; JST_GH_SM05B-GHS-TB_1x05-1MP_P1.25mm_Horizontal
M3: TS_RHT; JST_GH_SM05B-GHS-TB_1x05-1MP_P1.25mm_Horizontal
M5: PS2AVPort_SideMount; PS2_AVPort_Complete_MountSilk
P1, P2: PS2_ControlMount; PS2_BoardMountFootprint
P3: PS2_MemCardMount; PS2_MemCardMountPoints
U1: AudioAmp; PAM8803_AudioAmp
U2: 5VBuckBoost; PS2BuckBoost
U3: PJ30240; AudioJack_PJ30240
U4: Audio_Left; JST_ZE_SM02B-ZESS-TBT_1x02-1MP_P1.50mm_Horizontal
U5: Audio_Right; JST_ZE_SM02B-ZESS-TBT_1x02-1MP_P1.50mm_Horizontal
U6: XOST_Buttons
U7: NanoPiDUO2; NanoPIDUO2
U8: DMosfet_AO9926B; DualMosfet AO9926B

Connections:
GND: U3.1, U4.MP, U5.MP
unnamed: M1.2, U1.8
unnamed: M1.4, U1.10
unnamed: P1.11, P3.1
unnamed: P1.12, P3.2
unnamed: P1.13, P3.3
unnamed: P1.14, P3.4
unnamed: P1.15, P3.5
unnamed: P1.16, P3.6
unnamed: P1.17, P3.7
unnamed: P1.18, P3.8
unnamed: U1.4, U4.2
unnamed: U1.5, U3.2, U4.1
unnamed: U1.6, U5.2
unnamed: U1.7, U3.3, U5.1
